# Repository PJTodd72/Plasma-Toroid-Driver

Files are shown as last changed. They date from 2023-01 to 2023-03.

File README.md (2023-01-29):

# Plasma-Toroid-Driver

Version one of the Ki-Cad schematics and PCB layout of the Plasma Toroid generator driver circuits.

Also included are the Gerber files and interactive BOM generated by Ki-Cad.

Included is a simulation in LT spice of the driver circuit with no load.
This circuit oscillates as expected, however a simulation of the plasma load needs to be added for completion.

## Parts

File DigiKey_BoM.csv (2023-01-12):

Index | Quantity | Part Number | Manufacturer Part Number | Description | Customer Reference | Available | Backorder | Unit Price | Extended Price NZD
1 | 2 | 1928-1167-ND | FKP1U001004B00JSSD | CAP FILM 100PF 5% 2KVDC RAD |  | 2 | 0 | 1.33000 | 2.66
2 | 2 | IRFP260NPBF-ND | IRFP260NPBF | MOSFET N-CH 200V 50A TO247AC |  | 2 | 0 | 7.53000 | 15.06
3 | 1 | PDB12-H4301-103BF-ND | PDB12-H4301-103BF | POT 10K OHM 0.08W CARBON LINEAR |  | 1 | 0 | 2.20000 | 2.20
4 | 3 | A105938CT-ND | ROX2SJ1K0 | RES 1K OHM 5% 2W AXIAL |  | 3 | 0 | 0.71000 | 2.13
5 | 2 | 1N4742A-T50ACT-ND | 1N4742A-T50A | DIODE ZENER 12V 1W DO41 |  | 2 | 0 | 0.71000 | 1.42
6 | 2 | 1.5KE15CALFCT-ND | 1.5KE15CA | TVS DIODE 12.8VWM 21.2VC DO201 |  | 2 | 0 | 0.94000 | 1.88
7 | 2 | 495-4402-1-ND | B32529C1472K189 | CAP FILM 4700PF 10% 100VDC RAD |  | 2 | 0 | 0.57000 | 1.14
8 | 2 | 1189-1894-ND | 450BXC10MEFC10X20 | CAP ALUM 10UF 20% 450V RADIAL |  | 2 | 0 | 1.37000 | 2.74
9 | 1 | 277-1667-ND | 1935161 | TERM BLK 2POS SIDE ENTRY 5MM PCB |  | 1 | 0 | 0.96000 | 0.96

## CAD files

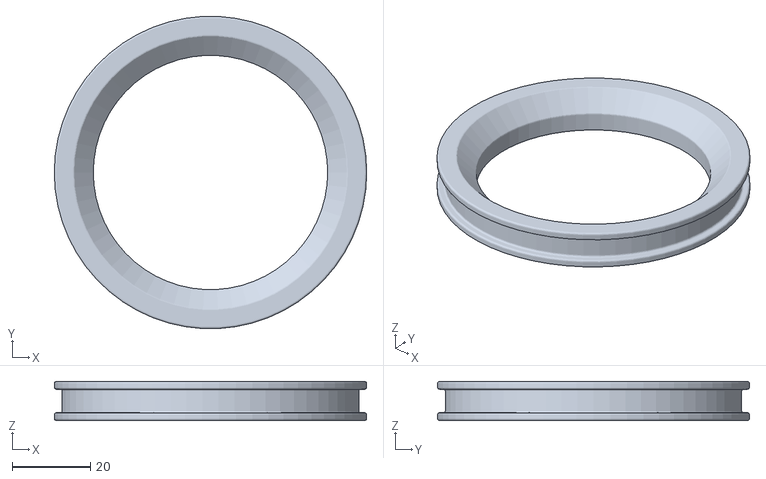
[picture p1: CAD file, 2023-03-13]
2.6mh core.stl
80.0 x 79.9 x 10.0

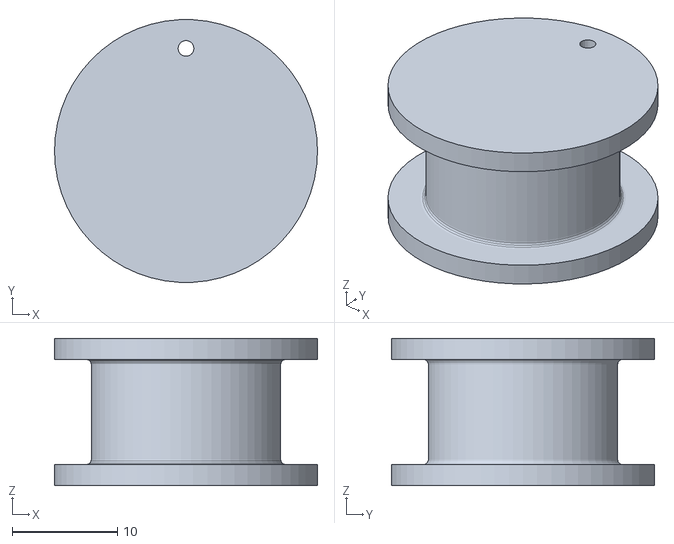
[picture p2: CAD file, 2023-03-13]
10mh core.stl
25.0 x 25.0 x 14.0

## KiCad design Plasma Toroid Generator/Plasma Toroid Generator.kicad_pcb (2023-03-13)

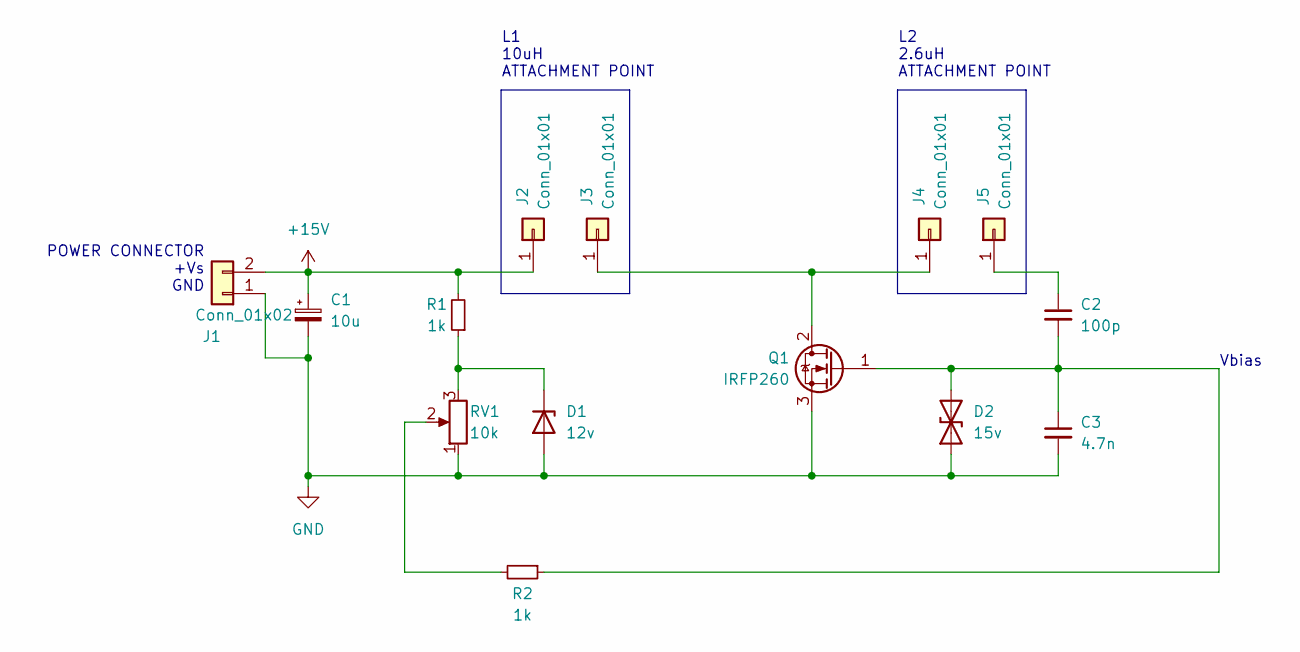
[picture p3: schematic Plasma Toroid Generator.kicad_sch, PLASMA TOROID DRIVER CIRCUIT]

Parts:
C1: 10u; CP_Radial_D10.0mm_P5.00mm
C2: 100p; C_Rect_L18.0mm_W5.0mm_P15.00mm_FKS3_FKP3
C3: 4.7n; C_Rect_L7.2mm_W2.5mm_P5.00mm_FKS2_FKP2_MKS2_MKP2
D1: 12v; D_DO-41_SOD81_P10.16mm_Horizontal
D2: 15v; D_DO-27_P15.24mm_Horizontal
J1: Conn_01x02; TerminalBlock_Phoenix_PT-1,5-2-5.0-H_1x02_P5.00mm_Horizontal
J2, J3, J4, J5: Conn_01x01; PinSocket_1x01_P2.54mm_Vertical
Q1: IRFP260; TO-247-3_Vertical
R1, R2: 1k; R_Axial_DIN0414_L11.9mm_D4.5mm_P15.24mm_Horizontal
RV1: 10k; Bourns PDB12-H

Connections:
+15V: C1.1, J1.2, J2.1, R1.2
GND: C1.2, C3.2, D1.2 (A), D2.1 (A1), J1.1, Q1.3 (S), RV1.1
unnamed: C2.1, J5.1
unnamed: C2.2, C3.1, D2.2 (A2), Q1.1 (G), R2.1
unnamed: D1.1 (K), R1.1, RV1.3
unnamed: J3.1, J4.1, Q1.2 (D)
unnamed: R2.2, RV1.2

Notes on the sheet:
POWER CONNECTOR +Vs GND
L1 10uH ATTACHMENT POINT
L2 2.6uH ATTACHMENT POINT
Vbias

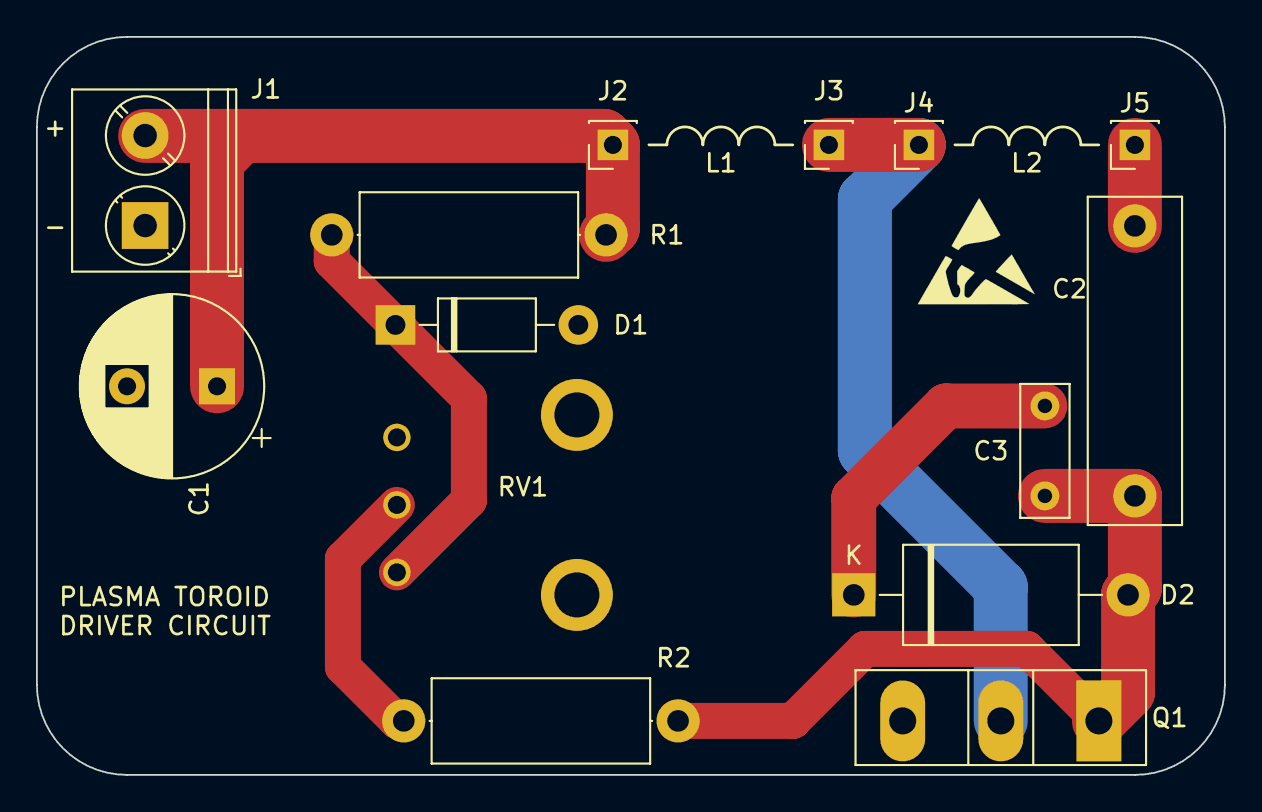
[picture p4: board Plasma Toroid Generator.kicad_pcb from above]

Board: 2 copper layers, 66.0 x 41.0 mm, 14 parts (0 on the bottom side), 7 nets.

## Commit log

2023-01-12 Version one of the schematics
    [Plasma Toroid Generator.kicad_pcb, Plasma Toroid Generator.kicad_sch]
2023-01-12 Added list of components as sourced from DigiKey
    [DigiKey_BoM.csv]
2023-01-12 Added LTSpice file that doesn't work as of yet
    [Plasma Toroid Generator.kicad_sch]
2023-01-26 Working simulation of the oscillating circuit
2023-01-29 Tested changing the oscillation frequency of the circuit
2023-02-06 Updated PCB layout to fix errors in cap placement
    [Plasma Toroid Generator.kicad_pcb, Plasma Toroid Generator.kicad_sch]
2023-03-13 Updates to model to accurately reflect the physical circuit
    [10mh core.stl, 2.6mh core.stl, Plasma Toroid Generator.kicad_pcb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]
